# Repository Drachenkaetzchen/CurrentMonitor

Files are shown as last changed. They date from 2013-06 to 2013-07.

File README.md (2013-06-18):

WARNING: This project is in transition to become a full-fledged MPPT charge controller for solar projects.
---------

CurrentMonitor is a dual-channel current and voltage monitor based on two INA138 current shunt monitoring ICs and an atmega168 and should run between 3.3 and 5V input (5V tested).

In the given configuration, the maximum values are:

* Input Voltage: 3.3V - 5.5V
* Maximum Monitoring Current: 2A
* Maximum Monitoring Voltage: 25V
* Current Gain: 2 (1mA = 2mV)
* Voltage Dividor: 5 (1M/200k)
* Self Power Usage: 5mA
* Voltage Resolution: 25mV
* Current Resolution: 2mA

The circuit is using the AVR's built-in ADC converter, which has a resolution of 10 bits (1024 values). By adjusting the resistors for the voltage divider and the gain resistor, you can adapt the circuit to your own needs. e.g. if the maximum voltage you want to measure is 10V, you can simply adjust the voltage dividor to 2 and thus have a voltage resolution of about 10mV. The minimum gain for the current is 1; so the minimum resolution one could gain is about 1mA. You could experiment with smaller gain values; the INA138 datasheet doesn't tell what happens then.

No communication or storage is present; you need to add your own I²C and serial communication busses to it.

The schematic uses a mix of through-hole and SMD components, because I wasn't sure if my chosen resitor values would fit; if they wouldn't, I could simply replace them. Feel free to replace them all with SMD resistors. But at the end, it turned out that my calculations were correct; but I haven't gotten around to change all components to SMD.

I'm using a 1% 10k gain resistor, which results in a gain of 2. You can use other values as well; refer to the INA138 datasheet where they listed.

As voltage and current monitoring is pretty much important, I'm planning to sell PCBs with serial, I²C and SD card logging capabilities.

Note that if you change the size of your shunt resistor, you'll also need to re-calculate the power dissipation capabilities. In the current configuration, a 0.5W resistor is suitable for the 2A maximum (voltage drop across the shunt resistor is 0.2 volts, which in turn gives 0.4 watts).

The schematic was done using Eagle 6.4.

The firmware isn't completed and will be uploaded as soon as it's done.

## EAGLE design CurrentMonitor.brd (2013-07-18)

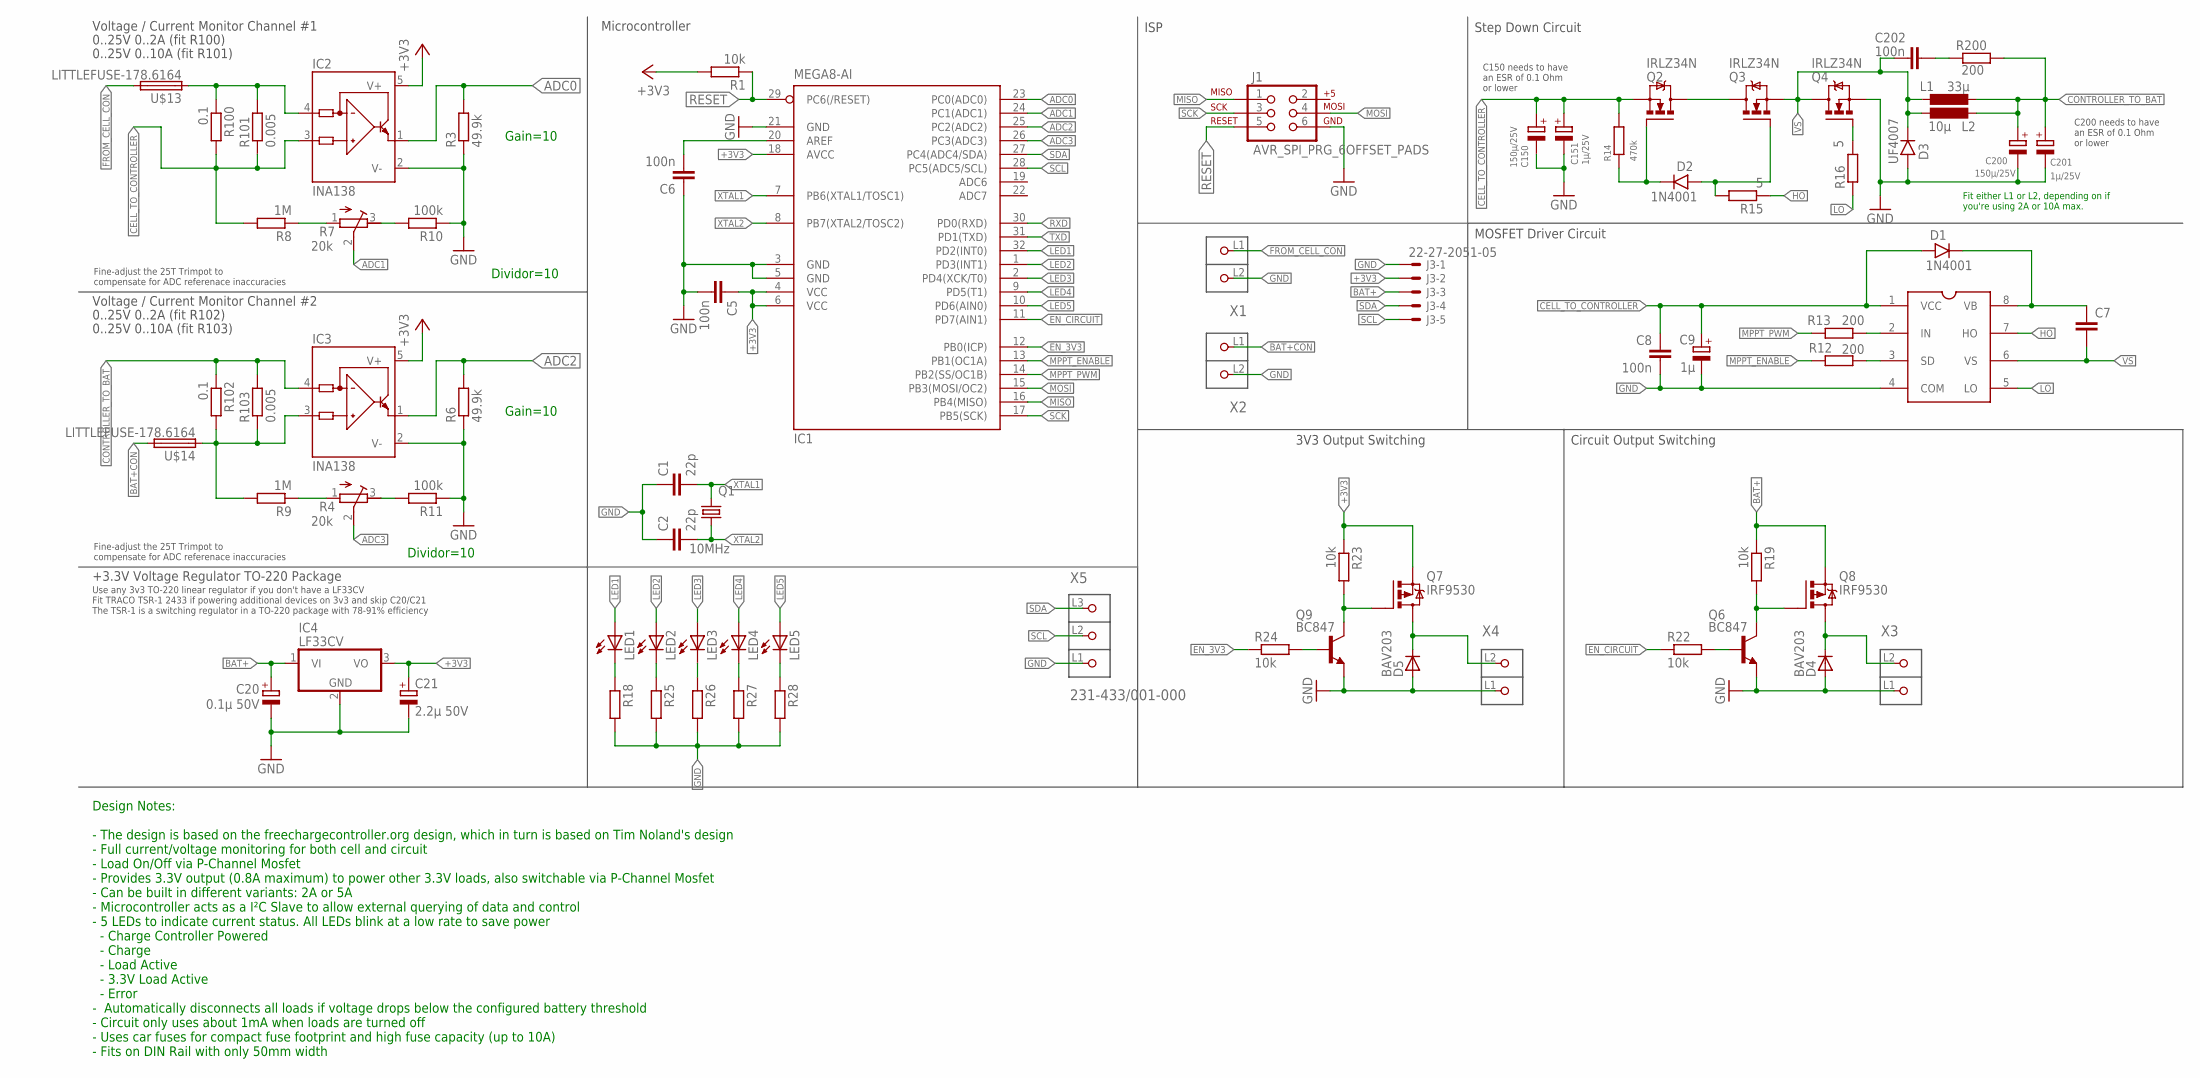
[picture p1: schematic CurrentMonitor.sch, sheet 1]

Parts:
C1, C2: 22p; C1206
C5, C6, C8, C202: 100n; C0805
C7: C-EUC0805; C0805
C9: 1µ; PANASONIC_A
C20: 0.1µ 50V; PANASONIC_A
C21: 2.2µ 50V; PANASONIC_B
C150, C200: 150µ/25V; PANASONIC_F
C151, C201: 1µ/25V; PANASONIC_B
D1, D2: 1N4001; DO41-3
D3: UF4007; DO41-3
D4, D5: BAV203; SOD80
IC1: MEGA8-AI; TQFP32-08
IC2, IC3: INA138; SOT23-5
IC4: LF33CV; TO220V
J1: AVR_SPI_PRG_6OFFSET_PADS; 2X3_OFFSET
J3: 22-27-2051-05; 6410-05
L1: 33µ; PISM
L2: 10µ; PISR
LED1, LED2, LED3, LED4, LED5: LEDCHIPLED_1206; CHIPLED_1206
Q1: 10MHz; CTS406
Q2, Q3, Q4: IRLZ34N; TO220BV
Q6, Q9: BC847; SOT23
Q7, Q8: IRF9530; TO220BV
R1, R19, R22, R23, R24: 10k; R0805
R3, R6: 49.9k; R0805
R4, R7: 20k; RTRIM64W
R8, R9: 1M; R0805
R10, R11: 100k; R0805
R12, R13, R200: 200; R0805
R14: 470k; R0805
R15, R16: 5; R0805
R18, R25, R26, R27, R28: R-EU_R0805; R0805
R100, R102: 0.1; R1206
R101, R103: 0.005; R2512
U$1: IR2104S
U$13, U$14: LITTLEFUSE-178.6164; LITTLEFUSE-178-6164
X1, X2, X3, X4: 231-432/001-000; P-231-432/001-000
X5: 231-433/001-000; P-231-433/001-000

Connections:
+3V3: C5.1, C21.+, IC1.4 (VCC), IC1.6 (VCC), IC1.18 (AVCC), IC2.5 (V+), IC3.5 (V+), IC4.3 (VO), J3.2, Q7.S, R1.2, R23.1
ADC0: IC1.23 (PC0(ADC0)), IC2.1 (OUT), R3.2
ADC1: IC1.24 (PC1(ADC1)), R7.2 (S)
ADC2: IC1.25 (PC2(ADC2)), IC3.1 (OUT), R6.2
ADC3: IC1.26 (PC3(ADC3)), R4.2 (S)
BAT+: C20.+, IC3.3 (IN+), IC4.1 (VI), J3.3, Q8.S, R9.2, R19.1, R102.2, R103.1, U$14.P$1 (1)
BAT+CON: U$14.P$2 (2), X2.L1 (P1)
CELL_TO_CONTROLLER: C8.1, C9.+, C150.+, C151.+, D1.A, IC2.3 (IN+), Q2.S, R8.2, R14.2, R100.2, R101.1, U$1.1 (VCC)
CONTROLLER_TO_BAT: C200.+, C201.+, IC3.4 (IN-), L1.2, L2.1, R102.1, R103.2, R200.2
EN_3V3: IC1.12 (PB0(ICP)), R24.1
EN_CIRCUIT: IC1.11 (PD7(AIN1)), R22.1
FROM_CELL: IC2.4 (IN-), R100.1, R101.2, U$13.P$1 (1)
FROM_CELL_CON: U$13.P$2 (2), X1.L1 (P1)
GND: C1.1, C2.1, C5.2, C6.1, C8.2, C9.-, C20.-, C21.-, C150.-, C151.-, C200.-, C201.-, D3.A, D4.2 (A), D5.2 (A), IC1.3 (GND), IC1.5 (GND), IC1.21 (GND), IC2.2 (V-), IC3.2 (V-), IC4.2 (GND), J1.6, J3.1, Q4.S, Q6.2 (E), Q9.2 (E), R3.1, R6.1, R10.1, R11.1, R18.2, R25.2, R26.2, R27.2, R28.2, U$1.4 (COM), X1.L2 (P2), X2.L2 (P2), X3.L1 (P1), X4.L1 (P1), X5.L1 (P1)
HO: R15.1, U$1.7 (HO)
LED1: IC1.32 (PD2(INT0)), LED1.A
LED2: IC1.1 (PD3(INT1)), LED2.A
LED3: IC1.2 (PD4(XCK/T0)), LED3.A
LED4: IC1.9 (PD5(T1)), LED4.A
LED5: IC1.10 (PD6(AIN0)), LED5.A
LO: R16.1, U$1.5 (LO)
MISO: IC1.16 (PB4(MISO)), J1.1
MOSI: IC1.15 (PB3(MOSI/OC2)), J1.4
MPPT_ENABLE: IC1.13 (PB1(OC1A)), R12.1
MPPT_PWM: IC1.14 (PB2(SS/OC1B)), R13.1
unnamed: C6.2, IC1.20 (AREF)
unnamed: R4.3 (E), R11.2
unnamed: R7.3 (E), R10.2
unnamed: R7.1 (A), R8.1
unnamed: R4.1 (A), R9.1
unnamed: LED1.C, R18.1
unnamed: R12.2, U$1.3 (SD)
unnamed: C7.1, D1.C, U$1.8 (VB)
unnamed: R13.2, U$1.2 (IN)
unnamed: Q4.G, R16.2
unnamed: D2.C, Q2.G, R14.1
unnamed: D2.A, Q3.G, R15.2
unnamed: Q2.D, Q3.D
unnamed: D4.1 (C), Q8.D, X3.L2 (P2)
unnamed: C202.1, R200.1
unnamed: LED2.C, R25.1
unnamed: Q6.3 (C), Q8.G, R19.2
unnamed: Q6.1 (B), R22.2
unnamed: Q7.G, Q9.3 (C), R23.2
unnamed: Q9.1 (B), R24.2
unnamed: D5.1 (C), Q7.D, X4.L2 (P2)
unnamed: LED3.C, R26.1
unnamed: LED4.C, R27.1
unnamed: LED5.C, R28.1
RESET: IC1.29 (PC6(/RESET)), J1.5, R1.1
RXD: IC1.30 (PD0(RXD))
SCK: IC1.17 (PB5(SCK)), J1.3
SCL: IC1.28 (PC5(ADC5/SCL)), J3.5, X5.L2 (P2)
SDA: IC1.27 (PC4(ADC4/SDA)), J3.4, X5.L3 (P3)
TXD: IC1.31 (PD1(TXD))
VS: C7.2, C202.2, D3.C, L1.1, L2.2, Q3.S, Q4.D, U$1.6 (VS)
XTAL1: C1.2, IC1.7 (PB6(XTAL1/TOSC1)), Q1.3 (2)
XTAL2: C2.2, IC1.8 (PB7(XTAL2/TOSC2)), Q1.1

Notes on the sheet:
Gain=10
Dividor=10
Voltage / Current Monitor Channel #1
Voltage / Current Monitor Channel #2
0..25V 0..2A (fit R100)
0..25V 0..2A (fit R102)
+3.3V Voltage Regulator TO-220 Package
Use any 3v3 TO-220 linear regulator if you don't have a LF33CV Fit TRACO TSR-1 2433 if powering additional devices on 3v3 and skip C20/C21 The TSR-1 is a switching regulator in a TO-220 package with 78-91% efficiency
Microcontroller
Fine-adjust the 25T Trimpot to compensate for ADC referenace inaccuracies
ISP
Step Down Circuit
MOSFET Driver Circuit
3V3 Output Switching
Circuit Output Switching
Fit either L1 or L2, depending on if you're using 2A or 10A max.
0..25V 0..10A (fit R101)
0..25V 0..10A (fit R103)
C200 needs to have an ESR of 0.1 Ohm or lower
C150 needs to have an ESR of 0.1 Ohm or lower
Design Notes: - The design is based on the freechargecontroller.org design, which in turn is based on Tim Noland's design - Full current/voltage monitoring for both cell and circuit - Load On/Off via P-Channel Mosfet - Provides 3.3V output (0.8A maximum) to power other 3.3V loads, also switchable v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

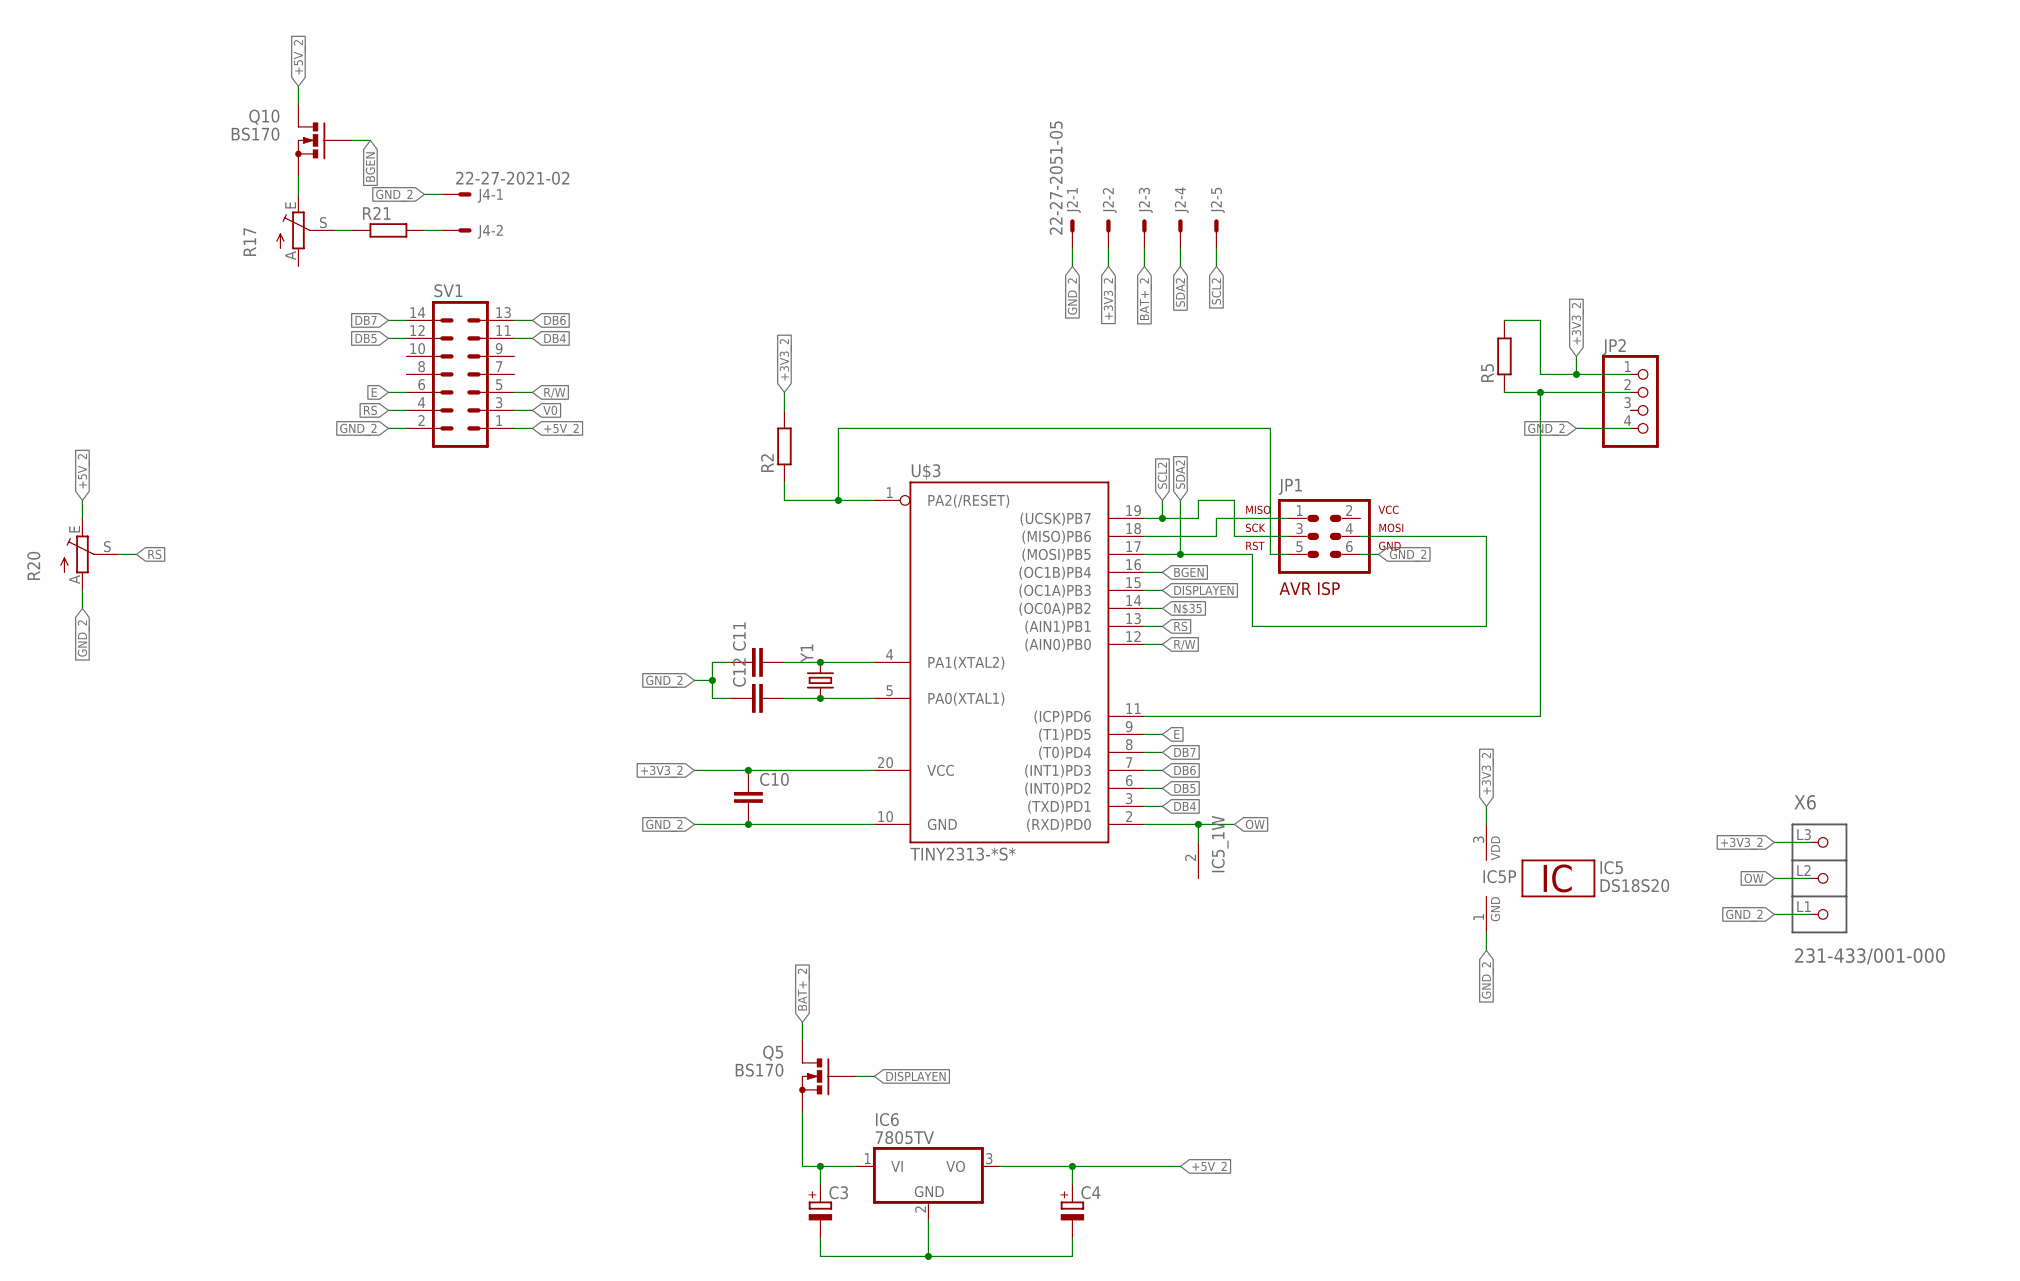
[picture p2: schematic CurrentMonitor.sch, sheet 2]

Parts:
C3, C4: CPOL-EUE3.5-8; E3,5-8
C10, C11, C12: C-EUC0805; C0805
IC5: DS18S20; TO92-
IC6: 7805TV; TO220V
J2: 22-27-2051-05; 6410-05
J4: 22-27-2021-02; 6410-02
JP1: AVR-ISP-6VERT; AVR-ISP-6
JP2: PINHD-1X4; 1X04
Q5, Q10: BS170; SOT54E
R2, R5, R21: R-EU_R0805; R0805
R17, R20: TRIM_EU-PT10; PT-10
SV1: ML14
U$3: TINY2313-*S*; SO20L$
X6: 231-433/001-000; P-231-433/001-000
Y1: CRYSTALHC49US; HC49US

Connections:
+3V3_2: C10.1, IC5.3 (VDD), J2.2, JP2.1, R2.2, R5.2, U$3.20 (VCC), X6.L3 (P3)
+5V_2: C4.+, IC6.3 (VO), Q10.D, R20.E, SV1.1
BAT+_2: J2.3, Q5.D
BGEN: Q10.G, U$3.16 ((OC1B)PB4)
DB4: SV1.11, U$3.3 ((TXD)PD1)
DB5: SV1.12, U$3.6 ((INT0)PD2)
DB6: SV1.13, U$3.7 ((INT1)PD3)
DB7: SV1.14, U$3.8 ((T0)PD4)
DISPLAYEN: Q5.G, U$3.15 ((OC1A)PB3)
E: SV1.6, U$3.9 ((T1)PD5)
GND_2: C3.-, C4.-, C10.2, C11.1, C12.1, IC5.1 (GND), IC6.2 (GND), J2.1, J4.1, JP1.6, JP2.4, R20.A, SV1.2, U$3.10 (GND), X6.L1 (P1)
unnamed: JP1.1, U$3.18 ((MISO)PB6)
unnamed: R17.S, R21.1
unnamed: JP2.2, R5.1, U$3.11 ((ICP)PD6)
unnamed: J4.2, R21.2
unnamed: JP1.5, R2.1, U$3.1 (PA2(/RESET))
unnamed: Q10.S, R17.E
unnamed: C11.2, U$3.4 (PA1(XTAL2)), Y1.2
unnamed: C12.2, U$3.5 (PA0(XTAL1)), Y1.1
unnamed: C3.+, IC6.1 (VI), Q5.S
OW: IC5.2 (1W), U$3.2 ((RXD)PD0), X6.L2 (P2)
R/W: SV1.5, U$3.12 ((AIN0)PB0)
RS: R20.S, SV1.4, U$3.13 ((AIN1)PB1)
SCL2: J2.5, JP1.3, U$3.19 ((UCSK)PB7)
SDA2: J2.4, JP1.4, U$3.17 ((MOSI)PB5)
V0: SV1.3

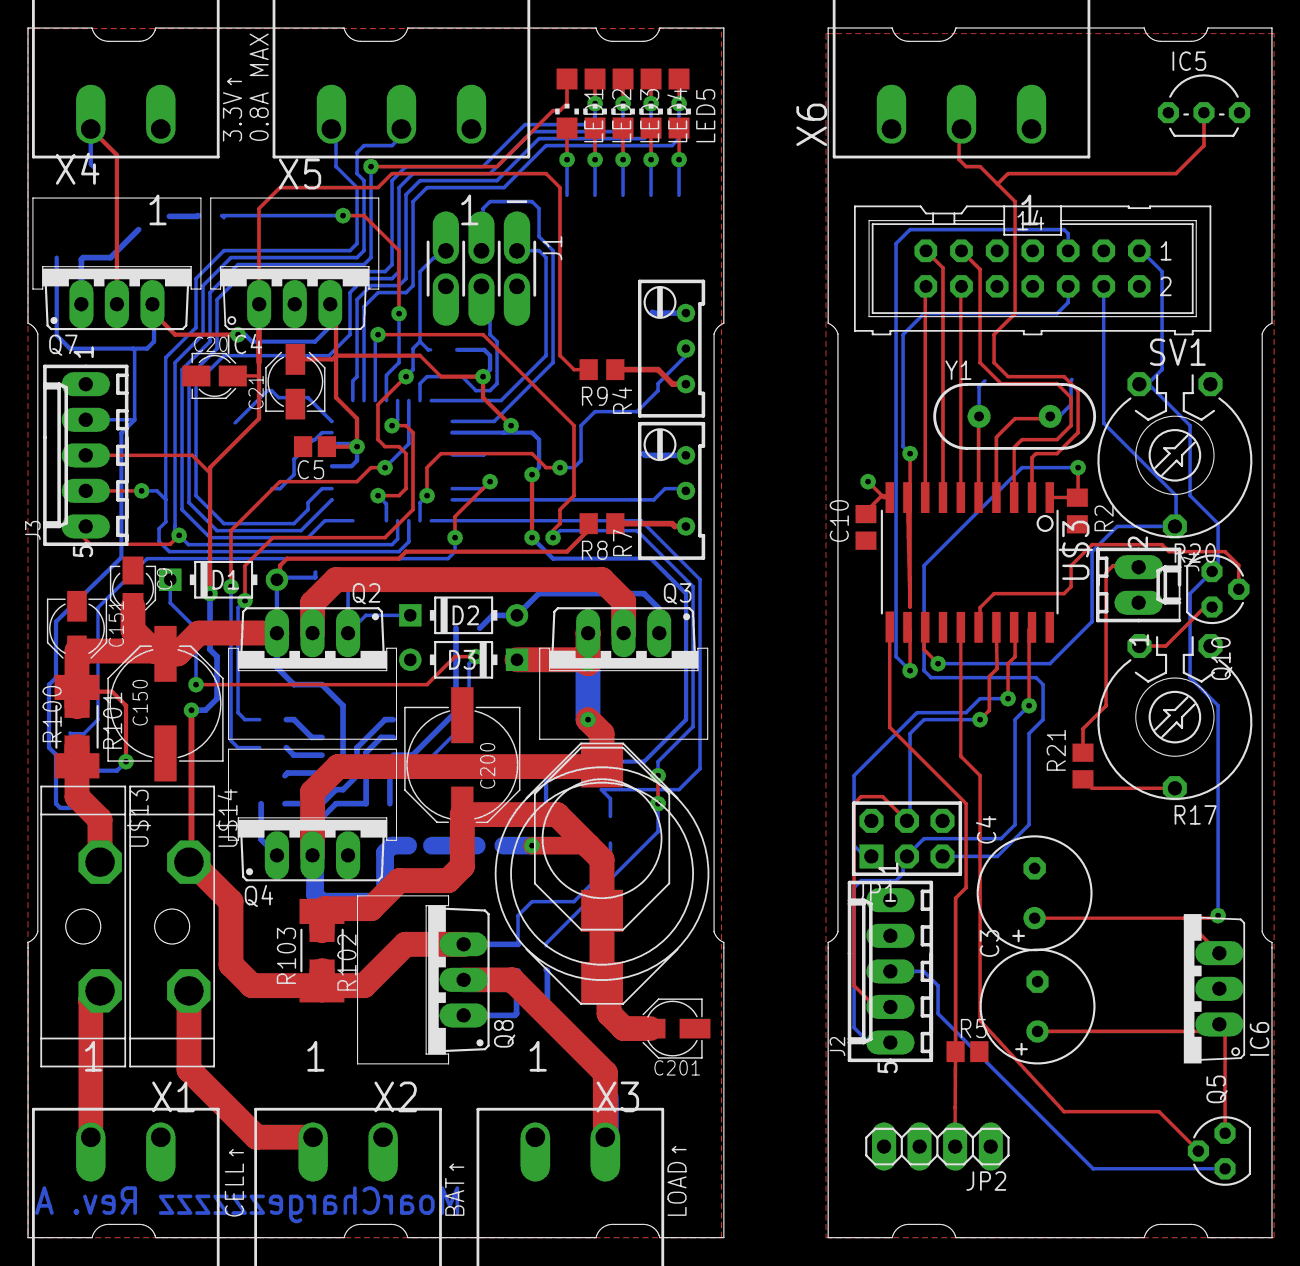
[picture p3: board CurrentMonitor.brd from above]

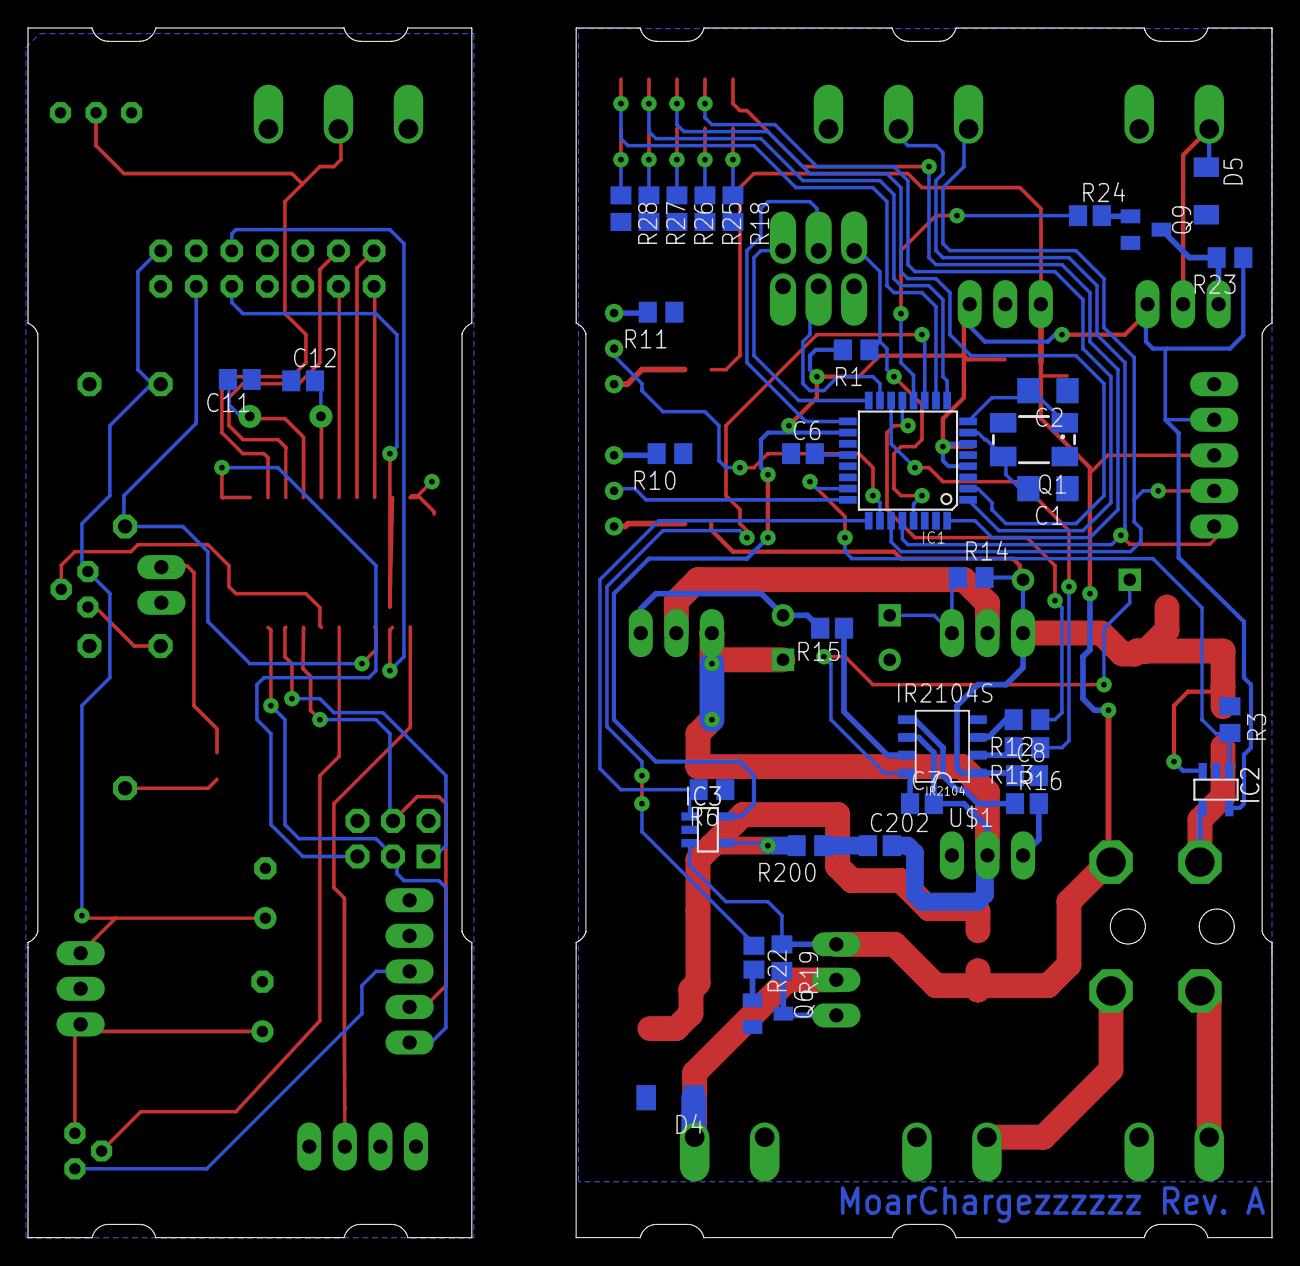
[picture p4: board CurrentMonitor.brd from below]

Board: 2 copper layers, 88.9 x 86.4 mm, 106 parts (37 on the bottom side), 81 nets.

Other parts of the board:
U$2: BC35,6
U$6, U$8, U$9, U$10, U$11, U$12: PR5/15-M3
U$7: BC53,6

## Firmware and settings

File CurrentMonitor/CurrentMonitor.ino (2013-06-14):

#include <OneWire.h>

OneWire ds(5);  // on pin 10

const int currentIn1 = A0;
const int currentIn2 = A2;
const int voltageIn1 = A1;
const int voltageIn2 = A3;

const int numReadings = 10;

float readings[4][numReadings];
int readingCounter[4];

const float resistorValue = 0.1;
const float voltageFactor = 5.6;
const float currentFactor = 1200;

float ADCFactor = 0.0;
float sensorValue = 0.0;        // value read from the pot

void setup() {
  // initialize serial communications at 9600 bps:
  ADCFactor = 5.0 / 1024.0;
  Serial.begin(9600);
}

void loop() {
  temp();
  Serial.print("0: " );                       
  Serial.print(getVoltage1());
  Serial.print("V");
  Serial.print(" ");
  Serial.print(getCurrent1());
  Serial.print("mA");
  Serial.println();
  
  Serial.print("1: " );                       
  Serial.print(getVoltage2());
  Serial.print("V");
  Serial.print(" ");
  Serial.print(getCurrent2());
  Serial.print("mA");
  Serial.println();

  delay(250);                     
}

float getVoltage1() {
   sensorValue = analogRead(voltageIn1);
   delay(10);

   return (sensorValue * voltageFactor * ADCFactor);
}

float getVoltage2() {
   sensorValue = analogRead(voltageIn2);

   delay(10);  
   return (sensorValue * voltageFactor * ADCFactor);
}

float getCurrent1 () {
  sensorValue = analogRead(currentIn1);
  delay(10);
  return (sensorValue * ADCFactor * currentFactor);
}

float getCurrent2 () {
  sensorValue = analogRead(currentIn2);
  delay(10);
  return (sensorValue * ADCFactor * currentFactor);
}

void temp (void) {
 byte i;
  byte present = 0;
  byte type_s;
  byte data[12];
  byte addr[8];
  float celsius, fahrenheit;
  
  if ( !ds.search(addr)) {
    ds.reset_search();
    delay(250);
    return;
  }
  
  for( i = 0; i < 8; i++) {
  }

  if (OneWire::crc8(addr, 7) != addr[7]) {
      return;
  }
  // the first ROM byte indicates which chip
  switch (addr[0]) {
    case 0x10:
      type_s = 1;
      break;
    case 0x28:
      type_s = 0;
      break;
    case 0x22:
      type_s = 0;
      break;
    default:
      return;
  } 

  ds.reset();
  ds.select(addr);
  ds.write(0x44, 1);        // start conversion, with parasite power on at the end
  
  delay(100);     // maybe 750ms is enough, maybe not
  // we might do a ds.depower() here, but the reset will take care of it.
  
  present = ds.reset();
  ds.select(addr);    
  ds.write(0xBE);         // Read Scratchpad

  for ( i = 0; i < 9; i++) {           // we need 9 bytes
    data[i] = ds.read();
  }

  // Convert the data to actual temperature
  // because the result is a 16 bit signed integer, it should
  // be stored to an "int16_t" type, which is always 16 bits
  // even when compiled on a 32 bit processor.
  int16_t raw = (data[1] << 8) | data[0];
  if (type_s) {
    raw = raw << 3; // 9 bit resolution default
    if (data[7] == 0x10) {
      // "count remain" gives full 12 bit resolution
      raw = (raw & 0xFFF0) + 12 - data[6];
    }
  } else {
    byte cfg = (data[4] & 0x60);
    // at lower res, the low bits are undefined, so let's zero them
    if (cfg == 0x00) raw = raw & ~7;  // 9 bit resolution, 93.75 ms
    else if (cfg == 0x20) raw = raw & ~3; // 10 bit res, 187.5 ms
    else if (cfg == 0x40) raw = raw & ~1; // 11 bit res, 375 ms
    //// default is 12 bit resolution, 750 ms conversion time
  }
  celsius = (float)raw / 16.0;
  fahrenheit = celsius * 1.8 + 32.0;
  Serial.print("T: ");
  Serial.println(celsius);
}

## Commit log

2013-06-14 Redesign first part, more to follow.
    [CurrentMonitor.sch]
2013-06-17 More updates
    [CurrentMonitor.sch]
2013-06-18 Updated README.md to reflect the transition to a full-fledged charge controller
2013-06-18 Added initial board
    [CurrentMonitor.brd, CurrentMonitor.sch]
2013-06-23 Added initial board. WARNING: This is an ugly board, which didn't receive much love because it's a prototype and I can't etch double-sided boards yet.
    [CurrentMonitor.brd, CurrentMonitor.sch]
2013-06-25 Second revision, dual layer
    [CurrentMonitor.brd, CurrentMonitor.sch]
2013-06-27 Added slightly larger traces and adjusted some components in order to support currents up to 10A
    [CurrentMonitor.brd, CurrentMonitor.sch]
2013-06-27 Added heatsink + LEDs
    [CurrentMonitor.brd, CurrentMonitor.sch]
2013-07-01 Foo (don't know what's changed, but I'm going to reroute everything)
    [CurrentMonitor.brd]
2013-07-18 Few fixes (forgot to commit, forgot what I have changed) ;)
    [CurrentMonitor.brd, CurrentMonitor.sch]

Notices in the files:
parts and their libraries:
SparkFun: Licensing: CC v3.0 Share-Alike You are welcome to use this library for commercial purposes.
